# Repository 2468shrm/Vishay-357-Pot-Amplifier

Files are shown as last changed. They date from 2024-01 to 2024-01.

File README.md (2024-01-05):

# Vishay-357-Pot-Amplifier

A unity-gain amplifier circut for the Vishay 357 series potentiometers. It mounts
on the back of the pot.

J1 Configures the voltage across the potentiometer, it allows for forward and
reverse adaption.
- Forward:  1-3 and 4-6
- Reverse:  3-5 and 2-4

J2 uses a socket header (female) to allow use of purchased FRC PWM cable to
connect between sensor and roboRIO.

J2 also provides power to the sensor. The circuit works with a VDD of 3.3V
to 5V, so this works with roboRIO as well as Feather and 3.3V MCU solutions.

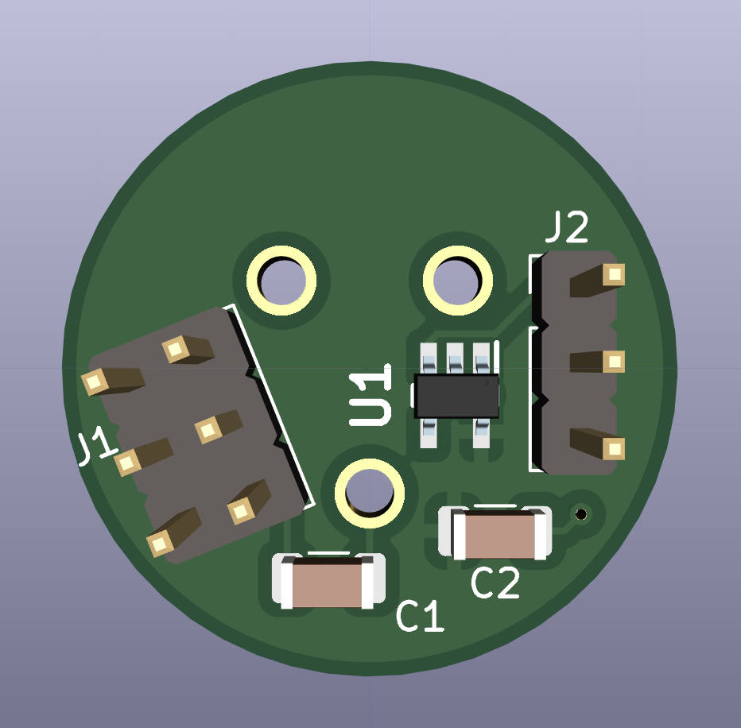
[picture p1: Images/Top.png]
Top View


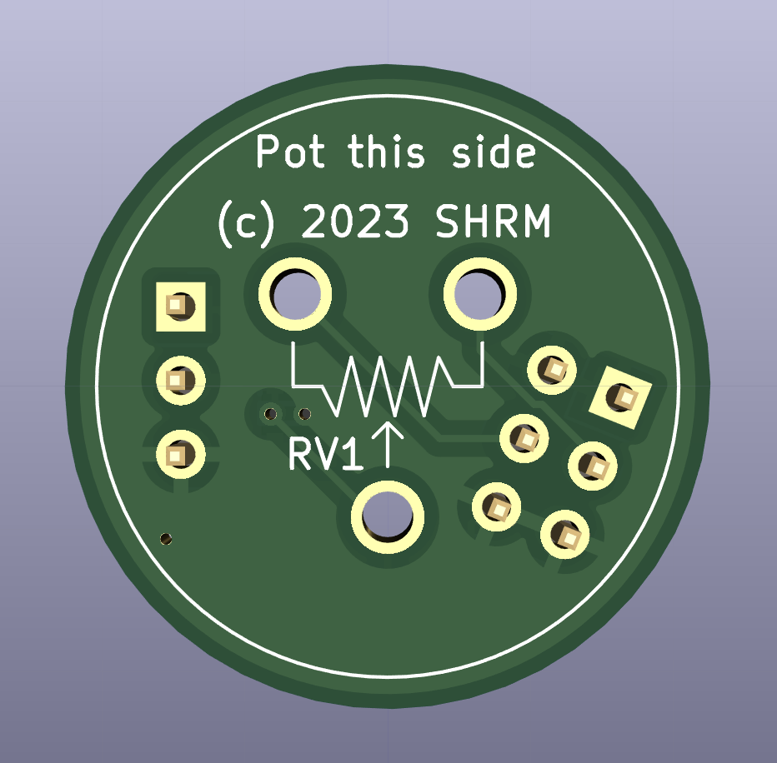
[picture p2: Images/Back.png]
Back View


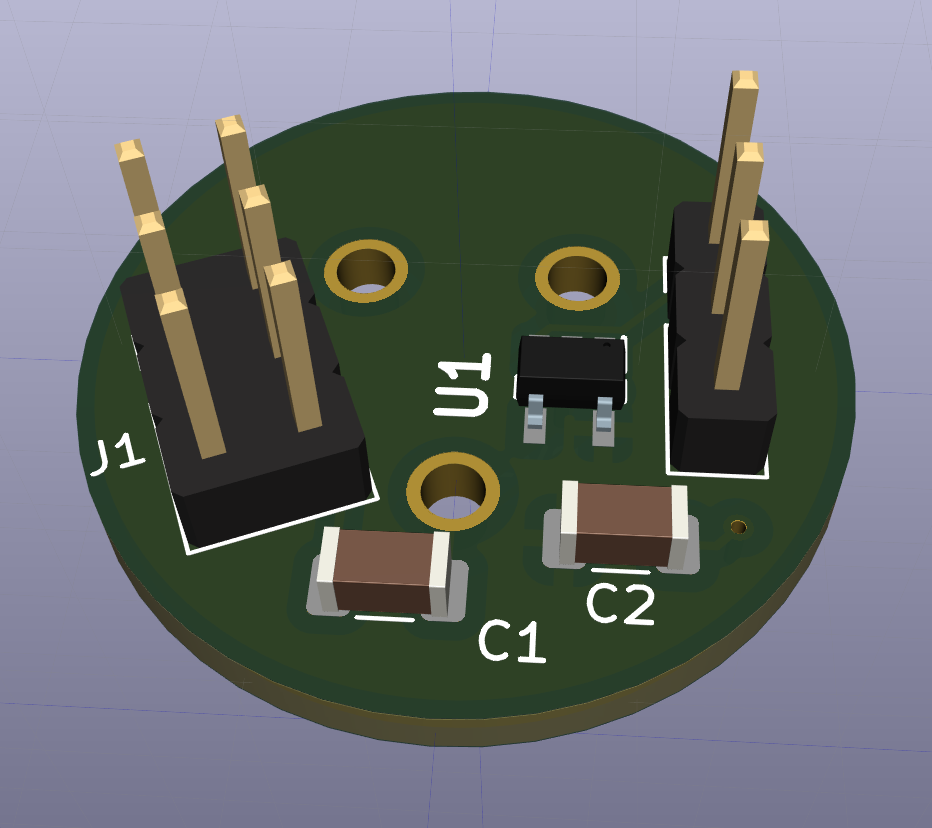
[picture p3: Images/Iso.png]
Iso View


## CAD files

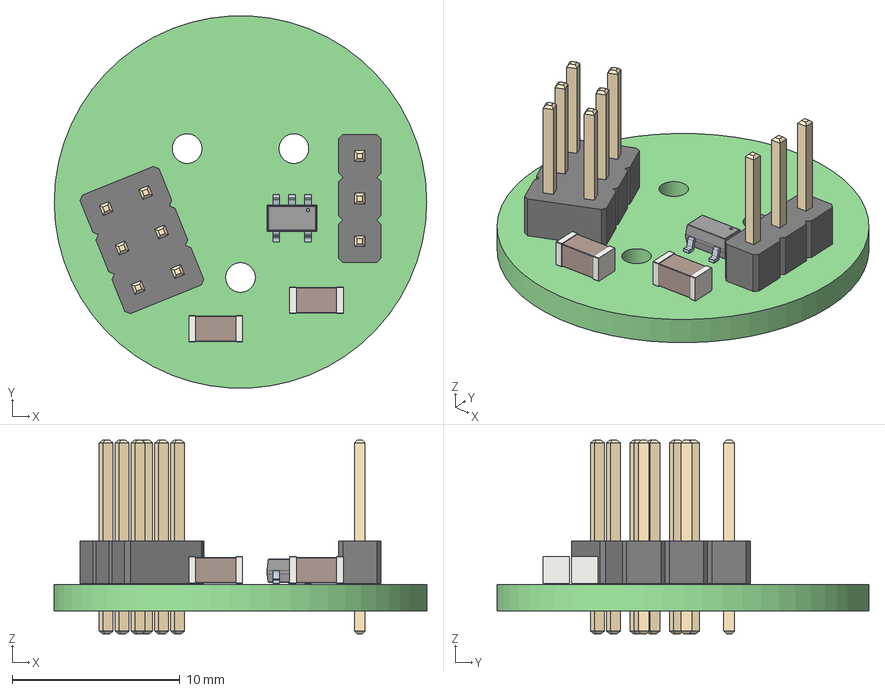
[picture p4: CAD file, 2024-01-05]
Gerbers/Vishay 357 Pot Amplifier.step
22.2 x 22.2 x 11.5 mm
_autosave-Vishay 357 Pot Amplifier PCB

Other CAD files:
Gerbers/APX321WG-7.step.SLDASM
Gerbers/Vishay 357 Pot Amplifier.SLDASM

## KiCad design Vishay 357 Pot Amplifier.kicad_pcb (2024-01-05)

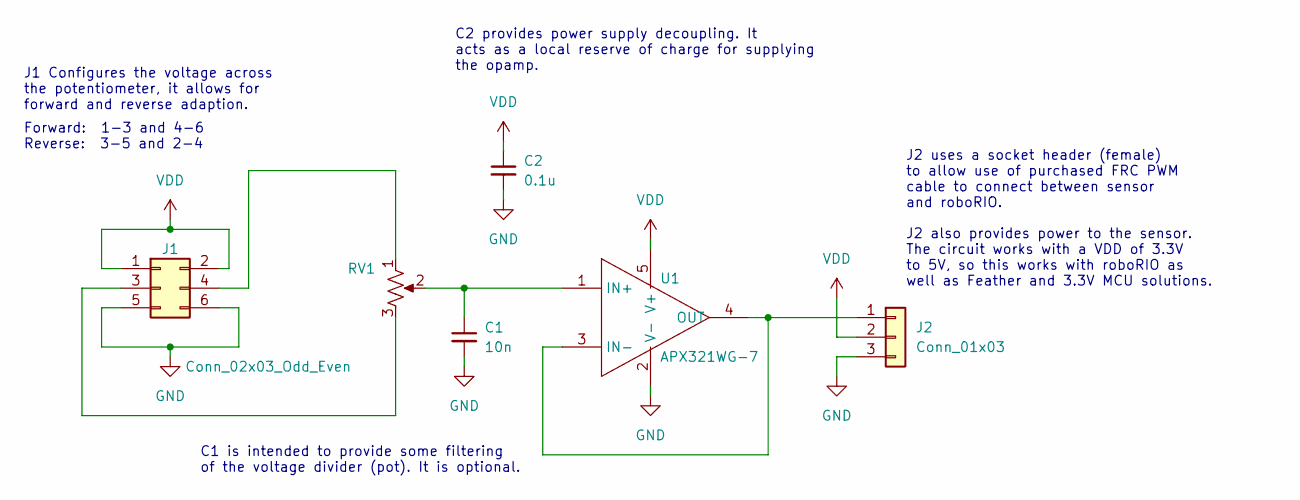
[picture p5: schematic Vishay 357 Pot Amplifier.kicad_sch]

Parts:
C1: 10n; C_1206_3216Metric
C2: 0.1u; C_1206_3216Metric
J1: Conn_02x03_Odd_Even; PinHeader_2x03_P2.54mm_Vertical
J2: Conn_01x03; PinHeader_1x03_P2.54mm_Vertical
RV1: R_Potentiometer_US; Vishay_357
U1: APX321WG-7; SOT95P285X145-5N; Manufacturer_Part_Number APX321WG-7; Mouser Part Number 621-APX321WG-7

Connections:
GND: C1.2, C2.2, J1.5, J1.6, J2.3, U1.2 (V-)
unnamed: C1.1, RV1.2, U1.1 (IN+)
unnamed: J1.4, RV1.1
unnamed: J2.1, U1.3 (IN-), U1.4 (OUT)
unnamed: J1.3, RV1.3
VDD: C2.1, J1.1, J1.2, J2.2, U1.5 (V+)

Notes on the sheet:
C2 provides power supply decoupling. It acts as a local reserve of charge for supplying the opamp.
C1 is intended to provide some filtering of the voltage divider (pot). It is optional.
Forward: 1-3 and 4-6 Reverse: 3-5 and 2-4
J2 also provides power to the sensor. The circuit works with a VDD of 3.3V to 5V, so this works with roboRIO as well as Feather and 3.3V MCU solutions.
J2 uses a socket header (female) to allow use of purchased FRC PWM cable to connect between sensor and roboRIO.
J1 Configures the voltage across the potentiometer, it allows for forward and reverse adaption.

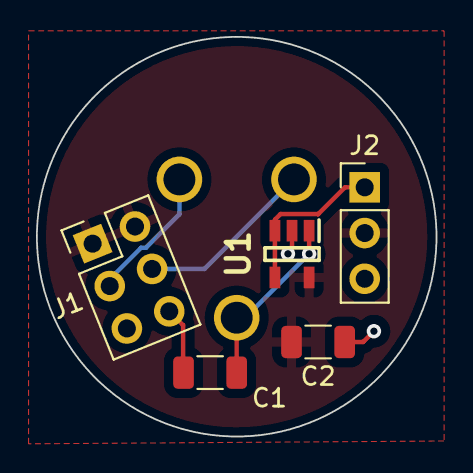
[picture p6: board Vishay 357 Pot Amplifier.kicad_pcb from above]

Board: 2 copper layers, 22.2 x 22.2 mm, 6 parts (1 on the bottom side), 6 nets.

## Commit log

2024-01-05 adding KiCAD files
    [Vishay 357 Pot Amplifier.kicad_pcb, Vishay 357 Pot Amplifier.kicad_sch]
2024-01-05 added manufacturing files (Gerbers)
    [APX321WG-7.step.SLDASM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]

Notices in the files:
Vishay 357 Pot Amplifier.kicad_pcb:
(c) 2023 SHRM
